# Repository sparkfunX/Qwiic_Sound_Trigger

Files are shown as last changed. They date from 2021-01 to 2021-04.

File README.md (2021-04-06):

# Qwiic Sound Trigger

A sound trigger which you can use on its own, or as part of your Qwiic system.

Qwiic Sound Trigger (SPX-17979) (https://www.sparkfun.com/products/17979)

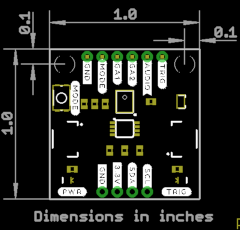
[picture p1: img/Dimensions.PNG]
Qwiic Sound Trigger (SPX-17979)


[Qwiic Sound Trigger (SPX-17979)](https://www.sparkfun.com/products/17979)

The Qwiic Sound Trigger is based on the VM1010 from Vesper Technologies and the TI PCA9536 GPIO expander.

The VM1010 is a clever little device which can be placed into a very low power "Wake On Sound" mode. When it detects a sound,
it wakes up and pulls its TRIG (D<sub>OUT</sub>) pin high. The VM1010 can then be placed into "Normal" mode by pulling the
MODE pin low; it then functions as a regular microphone. The analog microphone signal is available on the AUDIO (V<sub>OUT</sub>) pin.
All of this happens really quickly, within 50 _microseconds_ (_much_ faster than a capacitive MEMS microphone), so you don't miss
the start of the audio signal.

The noise threshold required to wake the VM1010 can be programmed via the resistance between pins GA1 and GA2. By default, the 20K
resistor on the breakout sets the noise threshold to close to the minimum (most sensitive) setting. You can increase the threshold
to maximum (least sensitive) by cutting the THRESH jumper. You can set it mid-way by adding your own resistor between breakout pins GA1 and GA2.

If you are using the VM1010 purely as a sound trigger, you need to reset it after each event by: pushing the MODE button;
pulling the MODE breakout pin low; or using the Qwiic bus to instruct the PCA9536 to pull the MODE signal low (the VM1010 MODE signal is connected to GPIO0).

You can use the TRIG (D<sub>OUT</sub>) breakout pin to generate an interrupt on your microcontroller. Or you can read (poll) its state via
the PCA9536 (the TRIG (D<sub>OUT</sub>) signal is connected to GPIO1).

There are two LEDs: one to indicate if the breakout is powered; and a second to show when a sound trigger has taken place. You can disable
either or both LEDs by cutting the LED jumpers on the back of the breakout.

As usual, the breakout includes I<sup>2</sup>C pull-up resistors. You can disable those if you need to by cutting the I2C jumpers.

The [**/Examples**](./Examples) folder contains two example sketches for the Arduino IDE:
- Example1 is a very simple example showing how to read the sound trigger TRIG signal via the PCA9536 GPIO1 pin and reset it via the MODE signal and GPIO2
- Example2 is a more complex example showing how you can capture and log the rising edge of the sound event with _nanosecond_ resolution using a ZED-F9P GNSS receiver

The [**/Utils**](./Utils) folder contains Python tools which can process the UBX TIM_TM2 data logged by Example2 and calculate the location of the sound events.

## Repository Contents
- [**/Examples**](./Examples) - Example sketches (.ino). Run these from the Arduino IDE
- [**/Utils**](./Utils) - Python tools to process the UBX TIM_TM2 data logged by Example2
- [**/Documents**](./Documents) - Datasheets etc. for both the VM1010 and PCA9536
- [**/Hardware**](./Hardware) - Eagle schematic and PCB design files
- [**LICENSE.md**](./LICENSE.md) contains the licence information

## Library

- **[SparkFun PCA9536 Arduino Library](https://github.com/sparkfun/SparkFun_PCA9536_Arduino_Library)** - Library for the TI PCA9536 4-Bit GPIO Expander

**_Your friends at SparkFun_**

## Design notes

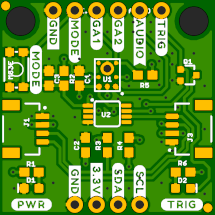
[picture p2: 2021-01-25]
img/Top.PNG

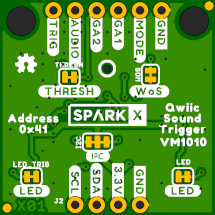
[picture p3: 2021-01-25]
img/Bottom.PNG

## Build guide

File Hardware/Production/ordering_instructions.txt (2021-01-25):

panel size, 143x143mm
PCB thickness, 1.6mm
number of layers, 2
soldermask color, Black
silkscreen color, White
oz copper, 1oz
finish, HASL lead free
stencils, top
pcs per panel, 25
min trace width, 0.2540mm / 0.0100in
min drill size, 0.3000mm / 0.0118in

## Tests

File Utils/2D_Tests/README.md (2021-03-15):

# 2D Tests

**python ..\Sound_Trigger_Analyzer_2D.py 1_TIM_TM2_A.ubx 1_TIM_TM2_B.ubx 1_TIM_TM2_C.ubx 10.0 11.0 8.0 20.0**

- Distance from sensor A to sensor B is 10.0m
- Distance from sensor A to sensor C is 11.0m
- Distance from sensor B to sensor C is 8.0m

- Test 1: Source located at (4.000,3.000)
- Test 2: Source located at (7.000,4.000)
- Test 3: Source located at (9.000,1.000) - i.e. East of C

**python ..\Sound_Trigger_Analyzer_2D.py 4_TIM_TM2_A.ubx 4_TIM_TM2_B.ubx 4_TIM_TM2_C.ubx 10.0 10.0 10.0 20.0**

- Distance from sensor A to sensor B is 10.0m
- Distance from sensor A to sensor C is 10.0m
- Distance from sensor B to sensor C is 10.0m

- Test 4: Source located at (5.000,2.887) - i.e. center of the triangle
- Test 5: Source located at (0.000,5.7735) - i.e. directly North of A on the circumference of the circle - outside of the triangle ABC
- Test 6: Source located at (-0.7735,2.8868) - i.e. West of A on the circumference of the circle - **FAILS**
- Test 7: Source located at (5.000,-2.8868) - i.e. due South of C on the circumference of the circle - **FAILS**

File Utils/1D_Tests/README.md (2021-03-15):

# 1D Tests

**python ..\Sound_Trigger_Analyzer_1D.py 1_TIM_TM2_1.ubx 1_TIM_TM2_2.ubx 10.0 20.0**

- Distance from sensor 1 to sensor 2 is 10.0m

- Test 1: Source located at sensor 1
- Test 2: Source located 3m from sensor 1
- Test 3: Source located 5m from sensor 1
- Test 4: Source located 7m from sensor 1
- Test 5: Source located at sensor 2

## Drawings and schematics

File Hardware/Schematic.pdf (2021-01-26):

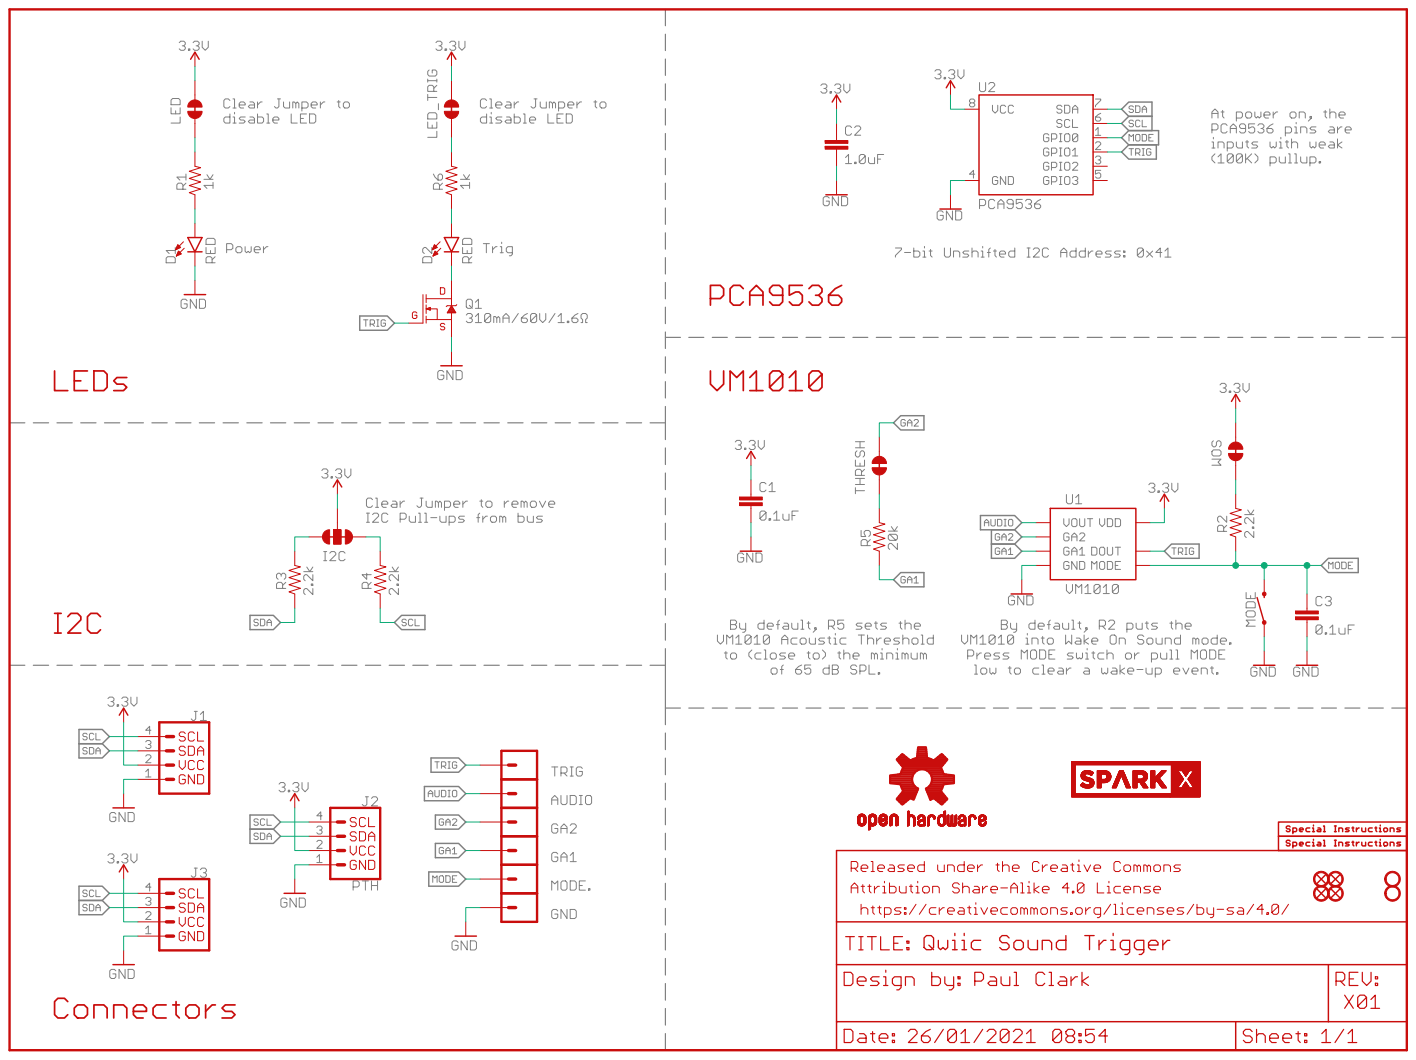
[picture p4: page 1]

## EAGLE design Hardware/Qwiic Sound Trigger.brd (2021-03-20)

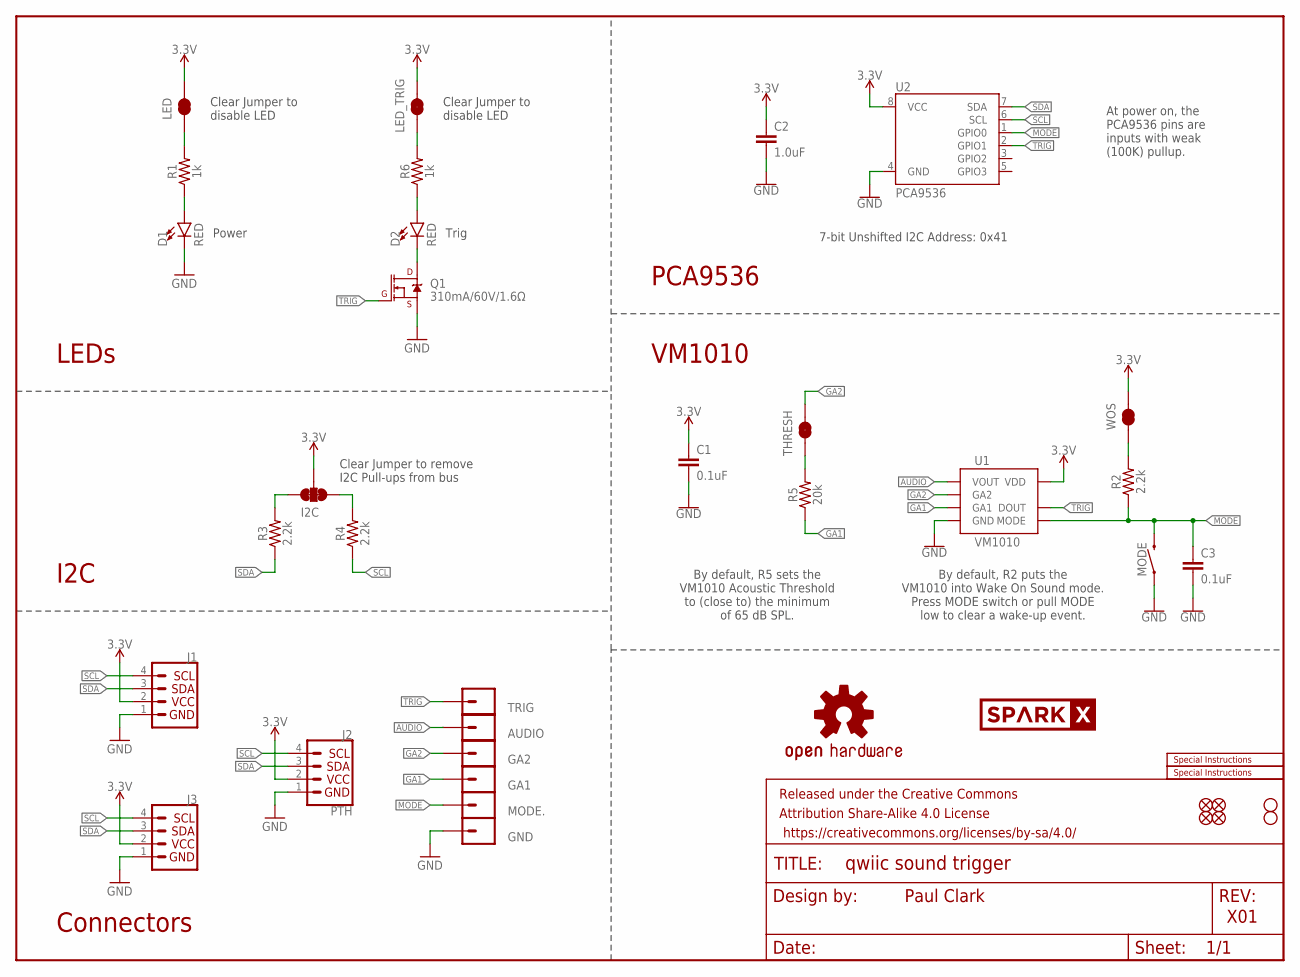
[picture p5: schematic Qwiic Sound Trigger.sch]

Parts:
AUDIO: CONN_01PTH_NO_SILK_YES_STOP; 1X01_NO_SILK
C1, C3: 0.1uF; 0603
C2: 1.0uF; 0603
D1, D2: RED; LED-0603
FRAME1: FRAME-LETTER; CREATIVE_COMMONS
GA1, GA2: CONN_01PTH_NO_SILK_YES_STOP; 1X01_NO_SILK
GND: CONN_01PTH_NO_SILK_YES_STOP; 1X01_NO_SILK
I2C: JUMPER-SMT_3_2-NC_TRACE_SILK; SMT-JUMPER_3_2-NC_TRACE_SILK
J1, J3: Qwiic Right Angle; JST04_1MM_RA
J2: PTH; 1X04_NO_SILK
JP1, JP2, JP5, JP6: FIDUCIAL1X2; FIDUCIAL-1X2
JP3, JP4: STAND-OFF
LED: JUMPER-SMT_2_NC_TRACE_SILK; SMT-JUMPER_2_NC_TRACE_SILK
LED_TRIG: JUMPER-SMT_2_NC_TRACE_SILK; SMT-JUMPER_2_NC_TRACE_SILK
LOGO1: OSHW-LOGOMINI; OSHW-LOGO-MINI
LOGO2: SPECIAL_INSTRUCTIONS-ORDERING; ORDERING_INSTRUCTIONS
LOGO3: SPECIAL_INSTRUCTIONS-PRODUCTION; PRODUCTION_INSTRUCTIONS
MODE: MOMENTARY-SWITCH-SPST-SMD-4.6X2.8MM; TACTILE_SWITCH_SMD_4.6X2.8MM
MODE.: CONN_01PTH_NO_SILK_YES_STOP; 1X01_NO_SILK
Q1: 310mA/60V/1.6Ω; SOT323
R1, R6: 1k; 0603
R2, R3, R4: 2.2k; 0603
R5: 20k; 0603
THRESH: JUMPER-SMT_2_NC_TRACE_SILK; SMT-JUMPER_2_NC_TRACE_SILK
TRIG: CONN_01PTH_NO_SILK_YES_STOP; 1X01_NO_SILK
U1: VM1010
U2: PCA9536; MSOP8
U$2: SPARKX-LOGO4; SPARKX-MEDIUM
WOS: JUMPER-SMT_2_NC_TRACE_SILK; SMT-JUMPER_2_NC_TRACE_SILK

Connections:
3.3V: C1.1, C2.1, I2C.2, J1.2, J2.2, J3.2, LED.2, LED_TRIG.2, U1.6 (VDD), U2.8 (VCC), WOS.2
AUDIO: AUDIO.1, U1.1 (VOUT)
GA1: GA1.1, R5.1, U1.3 (GA1)
GA2: GA2.1, THRESH.2, U1.2 (GA2)
GND: C1.2, C2.2, C3.2, D1.C, GND.1, J1.1, J2.1, J3.1, MODE.1, MODE.2 (1), Q1.2 (S), U1.4 (GND), U1.8 (GND), U2.4 (GND)
MODE: C3.1, MODE.3 (2), MODE.4 (2), MODE..1, R2.1, U1.5 (MODE), U2.1 (GPIO0)
unnamed: I2C.1, R4.2
unnamed: I2C.3, R3.2
unnamed: D1.A, R1.1
unnamed: LED.1, R1.2
unnamed: R2.2, WOS.1
unnamed: R5.2, THRESH.1
unnamed: D2.A, R6.1
unnamed: LED_TRIG.1, R6.2
unnamed: D2.C, Q1.3 (D)
SCL: J1.4, J2.4, J3.4, R4.1, U2.6 (SCL)
SDA: J1.3, J2.3, J3.3, R3.1, U2.7 (SDA)
TRIG: Q1.1 (G), TRIG.1, U1.7 (DOUT), U2.2 (GPIO1)

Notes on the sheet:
Paul Clark
X01
Clear Jumper to remove I2C Pull-ups from bus
Power
7-bit Unshifted I2C Address: 0x41
Connectors
At power on, the PCA9536 pins are inputs with weak (100K) pullup.
Clear Jumper to disable LED
LEDs
I2C
PCA9536
VM1010
By default, R2 puts the VM1010 into Wake On Sound mode. Press MODE switch or pull MODE low to clear a wake-up event.
By default, R5 sets the VM1010 Acoustic Threshold to (close to) the minimum of 65 dB SPL.
Trig

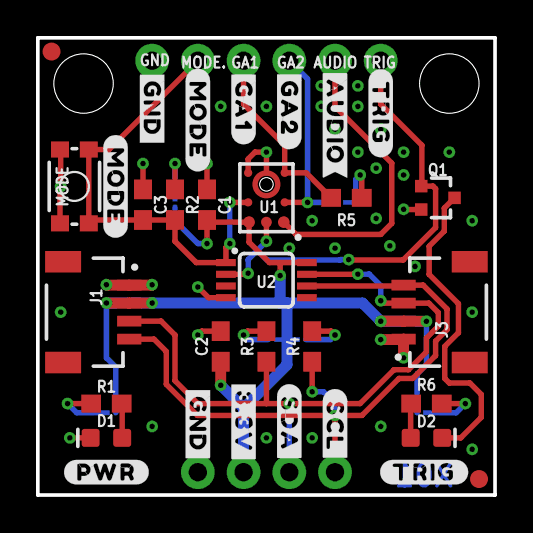
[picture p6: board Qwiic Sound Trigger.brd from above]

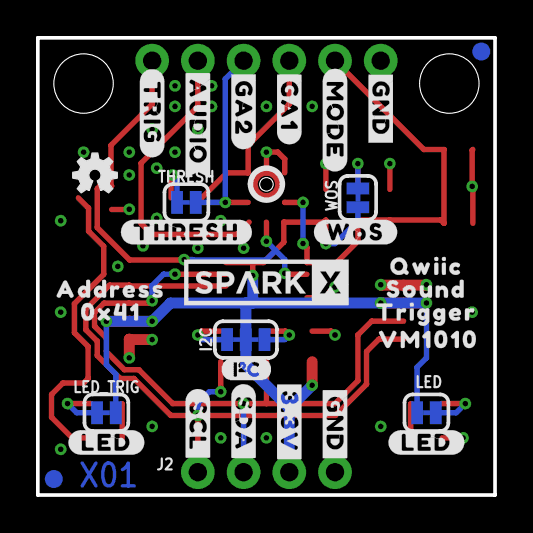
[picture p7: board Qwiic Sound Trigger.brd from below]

Board: 2 copper layers, 25.4 x 25.4 mm, 74 parts (31 on the bottom side), 18 nets.

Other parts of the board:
U$1, U$3: #GA1#0
U$4, U$5: #GA2#0
U$6, U$7: #AUDIO#0
U$8, U$9, U$25: #MODE#0
U$10: I_SUPER2_C-()-03
U$11, U$12, U$35: #TRIG#0
U$13: #PWR#0
U$14, U$36: #LED#0
U$15: #THRESH#0
U$16: #WOS#0
U$17, U$18, U$38, U$39: #GND#0
U$19, U$20: #3#3V#0
U$21, U$22: #SDA#0
U$23, U$24: #SCL#0
U$29: QWIIC0
U$30: SOUND0
U$31: TRIGGER0
U$32: VM10100
U$33: ADDRESS0
U$34: 0X410

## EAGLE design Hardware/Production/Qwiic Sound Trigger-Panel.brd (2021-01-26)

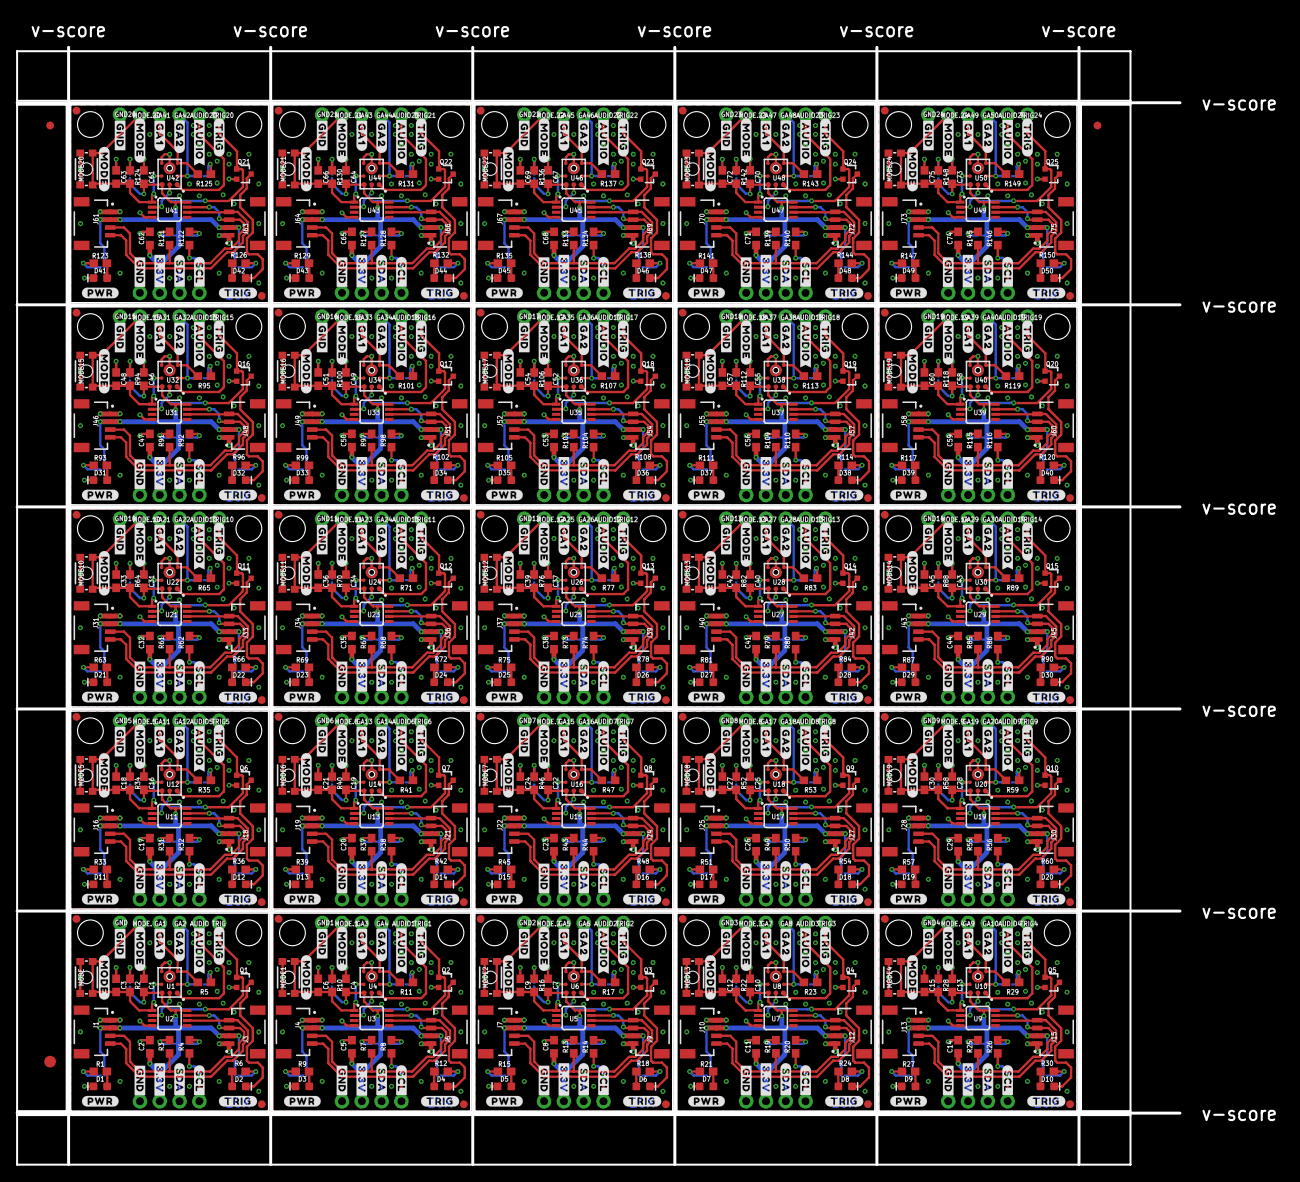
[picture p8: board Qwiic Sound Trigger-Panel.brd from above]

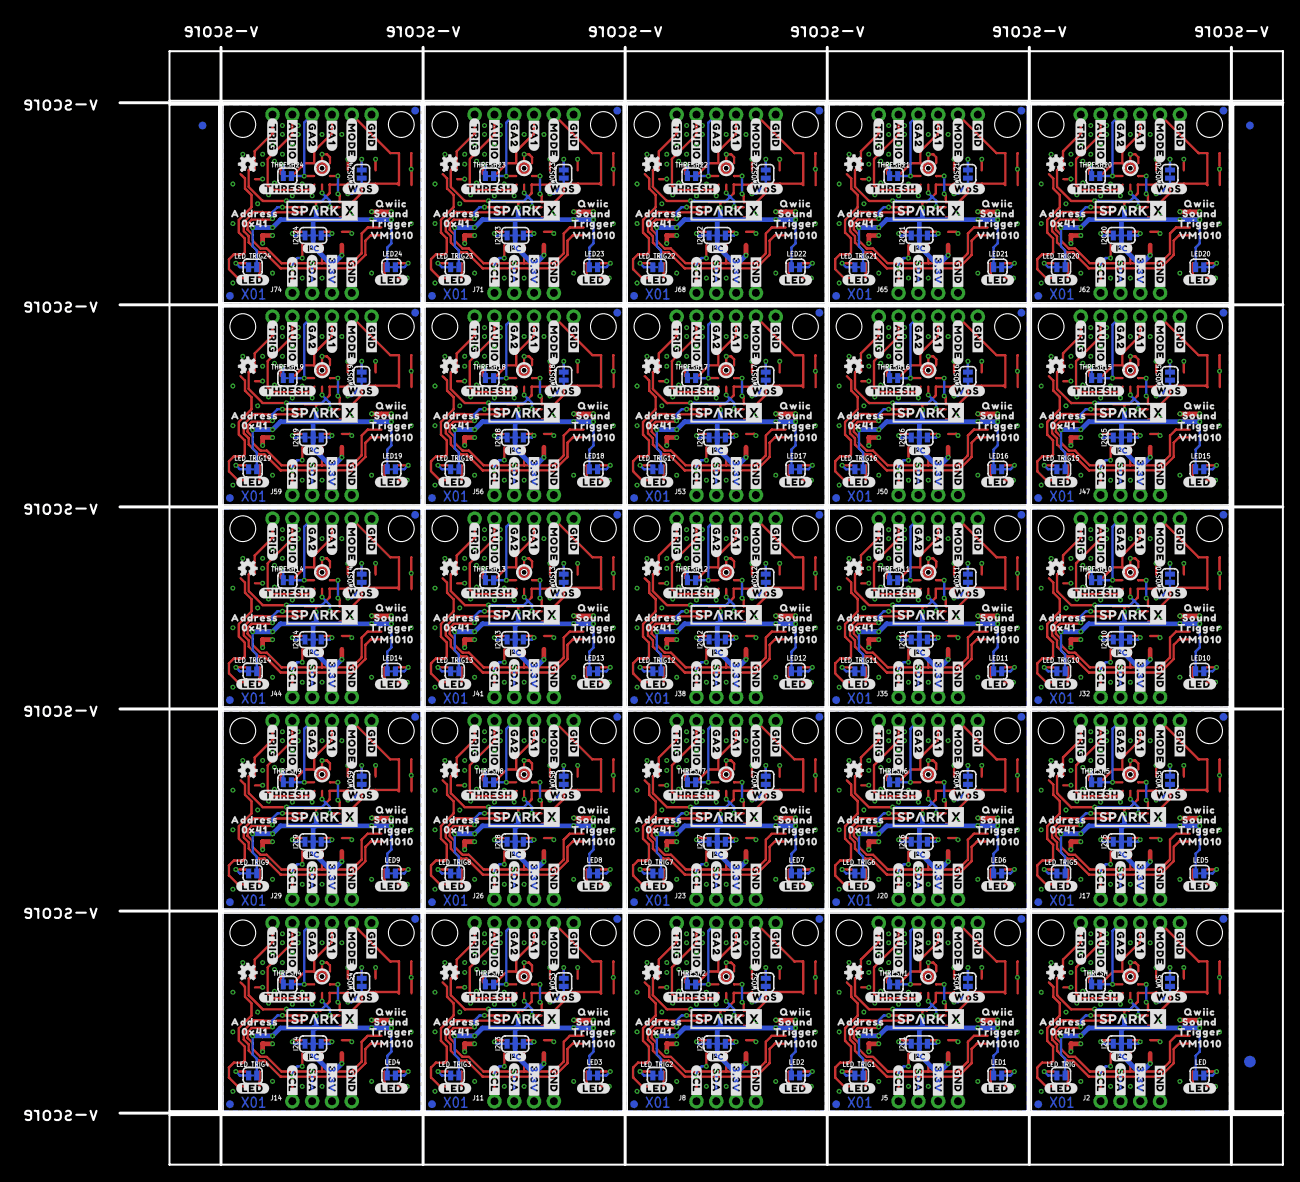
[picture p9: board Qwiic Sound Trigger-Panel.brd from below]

Board: 2 copper layers, 149.1 x 143.3 mm, 1831 parts (778 on the bottom side), 450 nets.

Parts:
AUDIO, AUDIO1, AUDIO2, AUDIO3, AUDIO4, AUDIO5, AUDIO6, AUDIO7, AUDIO8, AUDIO9, AUDIO10, AUDIO11, AUDIO12, AUDIO13, AUDIO14, AUDIO15, AUDIO16, AUDIO17, AUDIO18, AUDIO19, AUDIO20, AUDIO21, AUDIO22, AUDIO23, AUDIO24: 1X01_NO_SILK
C1, C3, C4, C6, C7, C9, C10, C12, C13, C15, C16, C18, C19, C21, C22, C24, C25, C27, C28, C30, C31, C33, C34, C36, C37, C39, C40, C42, C43, C45, C46, C48, C49, C51, C52, C54, C55, C57, C58, C60, C61, C63, C64, C66, C67, C69, C70, C72, C73, C75: 0.1uF; 0603
C2, C5, C8, C11, C14, C17, C20, C23, C26, C29, C32, C35, C38, C41, C44, C47, C50, C53, C56, C59, C62, C65, C68, C71, C74: 1.0uF; 0603
D1, D2, D3, D4, D5, D6, D7, D8, D9, D10, D11, D12, D13, D14, D15, D16, D17, D18, D19, D20, D21, D22, D23, D24, D25, D26, D27, D28, D29, D30, D31, D32, D33, D34, D35, D36, D37, D38, D39, D40, D41, D42, D43, D44, D45, D46, D47, D48, D49, D50: RED; LED-0603
E$1, E$2, E$3, E$4: FIDUCIAL-1X2
E$5, E$6: FIDUCIAL-1.5X3
GA1, GA2, GA3, GA4, GA5, GA6, GA7, GA8, GA9, GA10, GA11, GA12, GA13, GA14, GA15, GA16, GA17, GA18, GA19, GA20, GA21, GA22, GA23, GA24, GA25, GA26, GA27, GA28, GA29, GA30, GA31, GA32, GA33, GA34, GA35, GA36, GA37, GA38, GA39, GA40, GA41, GA42, GA43, GA44, GA45, GA46, GA47, GA48, GA49, GA50: 1X01_NO_SILK
GND, GND1, GND2, GND3, GND4, GND5, GND6, GND7, GND8, GND9, GND10, GND11, GND12, GND13, GND14, GND15, GND16, GND17, GND18, GND19, GND20, GND21, GND22, GND23, GND24: 1X01_NO_SILK
I2C, I2C1, I2C2, I2C3, I2C4, I2C5, I2C6, I2C7, I2C8, I2C9, I2C10, I2C11, I2C12, I2C13, I2C14, I2C15, I2C16, I2C17, I2C18, I2C19, I2C20, I2C21, I2C22, I2C23, I2C24: JUMPER-SMT_3_2-NC_TRACE_SILK; SMT-JUMPER_3_2-NC_TRACE_SILK
J1, J3, J4, J6, J7, J9, J10, J12, J13, J15, J16, J18, J19, J21, J22, J24, J25, J27, J28, J30, J31, J33, J34, J36, J37, J39, J40, J42, J43, J45, J46, J48, J49, J51, J52, J54, J55, J57, J58, J60, J61, J63, J64, J66, J67, J69, J70, J72, J73, J75: Qwiic Right Angle; JST04_1MM_RA
J2, J5, J8, J11, J14, J17, J20, J23, J26, J29, J32, J35, J38, J41, J44, J47, J50, J53, J56, J59, J62, J65, J68, J71, J74: PTH; 1X04_NO_SILK
JP1, JP2, JP5, JP6, JP9, JP10, JP11, JP12, JP15, JP16, JP17, JP18, JP21, JP22, JP23, JP24, JP27, JP28, JP29, JP30, JP33, JP34, JP35, JP36, JP39, JP40, JP41, JP42, JP45, JP46, JP47, JP48, JP51, JP52, JP53, JP54, JP57, JP58, JP59, JP60, JP63, JP64, JP65, JP66, JP69, JP70, JP71, JP72, JP75, JP76, JP77, JP78, JP81, JP82, JP83, JP84, JP87, JP88, JP89, JP90, JP93, JP94, JP95, JP96, JP99, JP100, JP101, JP102, JP105, JP106, JP107, JP108, JP111, JP112, JP113, JP114, JP117, JP118, JP119, JP120, JP123, JP124, JP125, JP126, JP129, JP130, JP131, JP132, JP135, JP136, JP137, JP138, JP141, JP142, JP143, JP144, JP147, JP148, JP149, JP150: FIDUCIAL1X2; FIDUCIAL-1X2
JP3, JP4, JP7, JP8, JP13, JP14, JP19, JP20, JP25, JP26, JP31, JP32, JP37, JP38, JP43, JP44, JP49, JP50, JP55, JP56, JP61, JP62, JP67, JP68, JP73, JP74, JP79, JP80, JP85, JP86, JP91, JP92, JP97, JP98, JP103, JP104, JP109, JP110, JP115, JP116, JP121, JP122, JP127, JP128, JP133, JP134, JP139, JP140, JP145, JP146: STAND-OFF
LED, LED1, LED2, LED3, LED4, LED5, LED6, LED7, LED8, LED9, LED10, LED11, LED12, LED13, LED14, LED15, LED16, LED17, LED18, LED19, LED20, LED21, LED22, LED23, LED24: SMT-JUMPER_2_NC_TRACE_SILK
LED_TRIG, LED_TRIG1, LED_TRIG2, LED_TRIG3, LED_TRIG4, LED_TRIG5, LED_TRIG6, LED_TRIG7, LED_TRIG8, LED_TRIG9, LED_TRIG10, LED_TRIG11, LED_TRIG12, LED_TRIG13, LED_TRIG14, LED_TRIG15, LED_TRIG16, LED_TRIG17, LED_TRIG18, LED_TRIG19, LED_TRIG20, LED_TRIG21, LED_TRIG22, LED_TRIG23, LED_TRIG24: SMT-JUMPER_2_NC_TRACE_SILK
LOGO1, LOGO4, LOGO7, LOGO10, LOGO13, LOGO16, LOGO19, LOGO22, LOGO25, LOGO28, LOGO31, LOGO34, LOGO37, LOGO40, LOGO43, LOGO46, LOGO49, LOGO52, LOGO55, LOGO58, LOGO61, LOGO64, LOGO67, LOGO70, LOGO73: OSHW-LOGOMINI; OSHW-LOGO-MINI
LOGO2, LOGO5, LOGO8, LOGO11, LOGO14, LOGO17, LOGO20, LOGO23, LOGO26, LOGO29, LOGO32, LOGO35, LOGO38, LOGO41, LOGO44, LOGO47, LOGO50, LOGO53, LOGO56, LOGO59, LOGO62, LOGO65, LOGO68, LOGO71, LOGO74: SPECIAL_INSTRUCTIONS-ORDERING; ORDERING_INSTRUCTIONS
LOGO3, LOGO6, LOGO9, LOGO12, LOGO15, LOGO18, LOGO21, LOGO24, LOGO27, LOGO30, LOGO33, LOGO36, LOGO39, LOGO42, LOGO45, LOGO48, LOGO51, LOGO54, LOGO57, LOGO60, LOGO63, LOGO66, LOGO69, LOGO72, LOGO75: SPECIAL_INSTRUCTIONS-PRODUCTION; PRODUCTION_INSTRUCTIONS
MODE, MODE1, MODE2, MODE3, MODE4, MODE5, MODE6, MODE7, MODE8, MODE9, MODE10, MODE11, MODE12, MODE13, MODE14, MODE15, MODE16, MODE17, MODE18, MODE19, MODE20, MODE21, MODE22, MODE23, MODE24: MOMENTARY-SWITCH-SPST-SMD-4.6X2.8MM; TACTILE_SWITCH_SMD_4.6X2.8MM
MODE., MODE.1, MODE.2, MODE.3, MODE.4, MODE.5, MODE.6, MODE.7, MODE.8, MODE.9, MODE.10, MODE.11, MODE.12, MODE.13, MODE.14, MODE.15, MODE.16, MODE.17, MODE.18, MODE.19, MODE.20, MODE.21, MODE.22, MODE.23, MODE.24: 1X01_NO_SILK
Q1, Q2, Q3, Q4, Q5, Q6, Q7, Q8, Q9, Q10, Q11, Q12, Q13, Q14, Q15, Q16, Q17, Q18, Q19, Q20, Q21, Q22, Q23, Q24, Q25: 310mA/60V/1.6Ω; SOT323
R1, R6, R9, R12, R15, R18, R21, R24, R27, R30, R33, R36, R39, R42, R45, R48, R51, R54, R57, R60, R63, R66, R69, R72, R75, R78, R81, R84, R87, R90, R93, R96, R99, R102, R105, R108, R111, R114, R117, R120, R123, R126, R129, R132, R135, R138, R141, R144, R147, R150: 1k; 0603
R2, R3, R4, R7, R8, R10, R13, R14, R16, R19, R20, R22, R25, R26, R28, R31, R32, R34, R37, R38, R40, R43, R44, R46, R49, R50, R52, R55, R56, R58, R61, R62, R64, R67, R68, R70, R73, R74, R76, R79, R80, R82, R85, R86, R88, R91, R92, R94, R97, R98, R100, R103, R104, R106, R109, R110, R112, R115, R116, R118, R121, R122, R124, R127, R128, R130, R133, R134, R136, R139, R140, R142, R145, R146, R148: 2.2k; 0603
R5, R11, R17, R23, R29, R35, R41, R47, R53, R59, R65, R71, R77, R83, R89, R95, R101, R107, R113, R119, R125, R131, R137, R143, R149: 20k; 0603
THRESH, THRESH1, THRESH2, THRESH3, THRESH4, THRESH5, THRESH6, THRESH7, THRESH8, THRESH9, THRESH10, THRESH11, THRESH12, THRESH13, THRESH14, THRESH15, THRESH16, THRESH17, THRESH18, THRESH19, THRESH20, THRESH21, THRESH22, THRESH23, THRESH24: SMT-JUMPER_2_NC_TRACE_SILK
TRIG, TRIG1, TRIG2, TRIG3, TRIG4, TRIG5, TRIG6, TRIG7, TRIG8, TRIG9, TRIG10, TRIG11, TRIG12, TRIG13, TRIG14, TRIG15, TRIG16, TRIG17, TRIG18, TRIG19, TRIG20, TRIG21, TRIG22, TRIG23, TRIG24: 1X01_NO_SILK
U1, U4, U6, U8, U10, U12, U14, U16, U18, U20, U22, U24, U26, U28, U30, U32, U34, U36, U38, U40, U42, U44, U46, U48, U50: VM1010
U2, U3, U5, U7, U9, U11, U13, U15, U17, U19, U21, U23, U25, U27, U29, U31, U33, U35, U37, U39, U41, U43, U45, U47, U49: PCA9536; MSOP8
U$1, U$3, U$28, U$37, U$73, U$74, U$108, U$109, U$143, U$144, U$178, U$179, U$213, U$214, U$248, U$249, U$283, U$284, U$318, U$319, U$353, U$354, U$388, U$389, U$423, U$424, U$458, U$459, U$493, U$494, U$528, U$529, U$563, U$564, U$598, U$599, U$633, U$634, U$668, U$669, U$703, U$704, U$738, U$739, U$773, U$774, U$808, U$809, U$843, U$844: #GA1#0
U$2, U$26, U$71, U$106, U$141, U$176, U$211, U$246, U$281, U$316, U$351, U$386, U$421, U$456, U$491, U$526, U$561, U$596, U$631, U$666, U$701, U$736, U$771, U$806, U$841: SPARKX-LOGO4; SPARKX-MEDIUM
U$4, U$5, U$40, U$41, U$75, U$76, U$110, U$111, U$145, U$146, U$180, U$181, U$215, U$216, U$250, U$251, U$285, U$286, U$320, U$321, U$355, U$356, U$390, U$391, U$425, U$426, U$460, U$461, U$495, U$496, U$530, U$531, U$565, U$566, U$600, U$601, U$635, U$636, U$670, U$671, U$705, U$706, U$740, U$741, U$775, U$776, U$810, U$811, U$845, U$846: #GA2#0
U$6, U$7, U$42, U$43, U$77, U$78, U$112, U$113, U$147, U$148, U$182, U$183, U$217, U$218, U$252, U$253, U$287, U$288, U$322, U$323, U$357, U$358, U$392, U$393, U$427, U$428, U$462, U$463, U$497, U$498, U$532, U$533, U$567, U$568, U$602, U$603, U$637, U$638, U$672, U$673, U$707, U$708, U$742, U$743, U$777, U$778, U$812, U$813, U$847, U$848: #AUDIO#0
U$8, U$9, U$25, U$44, U$45, U$70, U$79, U$80, U$105, U$114, U$115, U$140, U$149, U$150, U$175, U$184, U$185, U$210, U$219, U$220, U$245, U$254, U$255, U$280, U$289, U$290, U$315, U$324, U$325, U$350, U$359, U$360, U$385, U$394, U$395, U$420, U$429, U$430, U$455, U$464, U$465, U$490, U$499, U$500, U$525, U$534, U$535, U$560, U$569, U$570, U$595, U$604, U$605, U$630, U$639, U$640, U$665, U$674, U$675, U$700, U$709, U$710, U$735, U$744, U$745, U$770, U$779, U$780, U$805, U$814, U$815, U$840, U$849, U$850, U$875: #MODE#0
U$10, U$27, U$72, U$107, U$142, U$177, U$212, U$247, U$282, U$317, U$352, U$387, U$422, U$457, U$492, U$527, U$562, U$597, U$632, U$667, U$702, U$737, U$772, U$807, U$842: I_SUPER2_C-()-03
U$11, U$12, U$35, U$46, U$47, U$66, U$81, U$82, U$101, U$116, U$117, U$136, U$151, U$152, U$171, U$186, U$187, U$206, U$221, U$222, U$241, U$256, U$257, U$276, U$291, U$292, U$311, U$326, U$327, U$346, U$361, U$362, U$381, U$396, U$397, U$416, U$431, U$432, U$451, U$466, U$467, U$486, U$501, U$502, U$521, U$536, U$537, U$556, U$571, U$572, U$591, U$606, U$607, U$626, U$641, U$642, U$661, U$676, U$677, U$696, U$711, U$712, U$731, U$746, U$747, U$766, U$781, U$782, U$801, U$816, U$817, U$836, U$851, U$852, U$871: #TRIG#0
U$13, U$48, U$83, U$118, U$153, U$188, U$223, U$258, U$293, U$328, U$363, U$398, U$433, U$468, U$503, U$538, U$573, U$608, U$643, U$678, U$713, U$748, U$783, U$818, U$853: #PWR#0
U$14, U$36, U$49, U$67, U$84, U$102, U$119, U$137, U$154, U$172, U$189, U$207, U$224, U$242, U$259, U$277, U$294, U$312, U$329, U$347, U$364, U$382, U$399, U$417, U$434, U$452, U$469, U$487, U$504, U$522, U$539, U$557, U$574, U$592, U$609, U$627, U$644, U$662, U$679, U$697, U$714, U$732, U$749, U$767, U$784, U$802, U$819, U$837, U$854, U$872: #LED#0
U$15, U$50, U$85, U$120, U$155, U$190, U$225, U$260, U$295, U$330, U$365, U$400, U$435, U$470, U$505, U$540, U$575, U$610, U$645, U$680, U$715, U$750, U$785, U$820, U$855: #THRESH#0
U$16, U$51, U$86, U$121, U$156, U$191, U$226, U$261, U$296, U$331, U$366, U$401, U$436, U$471, U$506, U$541, U$576, U$611, U$646, U$681, U$716, U$751, U$786, U$821, U$856: #WOS#0
U$17, U$18, U$38, U$39, U$52, U$53, U$68, U$69, U$87, U$88, U$103, U$104, U$122, U$123, U$138, U$139, U$157, U$158, U$173, U$174, U$192, U$193, U$208, U$209, U$227, U$228, U$243, U$244, U$262, U$263, U$278, U$279, U$297, U$298, U$313, U$314, U$332, U$333, U$348, U$349, U$367, U$368, U$383, U$384, U$402, U$403, U$418, U$419, U$437, U$438, U$453, U$454, U$472, U$473, U$488, U$489, U$507, U$508, U$523, U$524, U$542, U$543, U$558, U$559, U$577, U$578, U$593, U$594, U$612, U$613, U$628, U$629, U$647, U$648, U$663, U$664, U$682, U$683, U$698, U$699, U$717, U$718, U$733, U$734, U$752, U$753, U$768, U$769, U$787, U$788, U$803, U$804, U$822, U$823, U$838, U$839, U$857, U$858, U$873, U$874: #GND#0
U$19, U$20, U$54, U$55, U$89, U$90, U$124, U$125, U$159, U$160, U$194, U$195, U$229, U$230, U$264, U$265, U$299, U$300, U$334, U$335, U$369, U$370, U$404, U$405, U$439, U$440, U$474, U$475, U$509, U$510, U$544, U$545, U$579, U$580, U$614, U$615, U$649, U$650, U$684, U$685, U$719, U$720, U$754, U$755, U$789, U$790, U$824, U$825, U$859, U$860: #3#3V#0
U$21, U$22, U$56, U$57, U$91, U$92, U$126, U$127, U$161, U$162, U$196, U$197, U$231, U$232, U$266, U$267, U$301, U$302, U$336, U$337, U$371, U$372, U$406, U$407, U$441, U$442, U$476, U$477, U$511, U$512, U$546, U$547, U$581, U$582, U$616, U$617, U$651, U$652, U$686, U$687, U$721, U$722, U$756, U$757, U$791, U$792, U$826, U$827, U$861, U$862: #SDA#0
U$23, U$24, U$58, U$59, U$93, U$94, U$128, U$129, U$163, U$164, U$198, U$199, U$233, U$234, U$268, U$269, U$303, U$304, U$338, U$339, U$373, U$374, U$408, U$409, U$443, U$444, U$478, U$479, U$513, U$514, U$548, U$549, U$583, U$584, U$618, U$619, U$653, U$654, U$688, U$689, U$723, U$724, U$758, U$759, U$793, U$794, U$828, U$829, U$863, U$864: #SCL#0
U$29, U$60, U$95, U$130, U$165, U$200, U$235, U$270, U$305, U$340, U$375, U$410, U$445, U$480, U$515, U$550, U$585, U$620, U$655, U$690, U$725, U$760, U$795, U$830, U$865: QWIIC0
U$30, U$61, U$96, U$131, U$166, U$201, U$236, U$271, U$306, U$341, U$376, U$411, U$446, U$481, U$516, U$551, U$586, U$621, U$656, U$691, U$726, U$761, U$796, U$831, U$866: SOUND0
U$31, U$62, U$97, U$132, U$167, U$202, U$237, U$272, U$307, U$342, U$377, U$412, U$447, U$482, U$517, U$552, U$587, U$622, U$657, U$692, U$727, U$762, U$797, U$832, U$867: TRIGGER0
U$32, U$63, U$98, U$133, U$168, U$203, U$238, U$273, U$308, U$343, U$378, U$413, U$448, U$483, U$518, U$553, U$588, U$623, U$658, U$693, U$728, U$763, U$798, U$833, U$868: VM10100
U$33, U$64, U$99, U$134, U$169, U$204, U$239, U$274, U$309, U$344, U$379, U$414, U$449, U$484, U$519, U$554, U$589, U$624, U$659, U$694, U$729, U$764, U$799, U$834, U$869: ADDRESS0
U$34, U$65, U$100, U$135, U$170, U$205, U$240, U$275, U$310, U$345, U$380, U$415, U$450, U$485, U$520, U$555, U$590, U$625, U$660, U$695, U$730, U$765, U$800, U$835, U$870: 0X410
WOS, WOS1, WOS2, WOS3, WOS4, WOS5, WOS6, WOS7, WOS8, WOS9, WOS10, WOS11, WOS12, WOS13, WOS14, WOS15, WOS16, WOS17, WOS18, WOS19, WOS20, WOS21, WOS22, WOS23, WOS24: SMT-JUMPER_2_NC_TRACE_SILK

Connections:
3.3V: C1.1, C2.1, I2C.2, J1.2, J2.2, J3.2, LED.2, LED_TRIG.2, U1.6, U2.8, WOS.2
3.3V1: C4.1, C5.1, I2C1.2, J4.2, J5.2, J6.2, LED1.2, LED_TRIG1.2, U3.8, U4.6, WOS1.2
3.3V2: C7.1, C8.1, I2C2.2, J7.2, J8.2, J9.2, LED2.2, LED_TRIG2.2, U5.8, U6.6, WOS2.2
3.3V3: C10.1, C11.1, I2C3.2, J10.2, J11.2, J12.2, LED3.2, LED_TRIG3.2, U7.8, U8.6, WOS3.2
3.3V4: C13.1, C14.1, I2C4.2, J13.2, J14.2, J15.2, LED4.2, LED_TRIG4.2, U9.8, U10.6, WOS4.2
3.3V5: C16.1, C17.1, I2C5.2, J16.2, J17.2, J18.2, LED5.2, LED_TRIG5.2, U11.8, U12.6, WOS5.2
3.3V6: C19.1, C20.1, I2C6.2, J19.2, J20.2, J21.2, LED6.2, LED_TRIG6.2, U13.8, U14.6, WOS6.2
3.3V7: C22.1, C23.1, I2C7.2, J22.2, J23.2, J24.2, LED7.2, LED_TRIG7.2, U15.8, U16.6, WOS7.2
3.3V8: C25.1, C26.1, I2C8.2, J25.2, J26.2, J27.2, LED8.2, LED_TRIG8.2, U17.8, U18.6, WOS8.2
3.3V9: C28.1, C29.1, I2C9.2, J28.2, J29.2, J30.2, LED9.2, LED_TRIG9.2, U19.8, U20.6, WOS9.2
3.3V10: C31.1, C32.1, I2C10.2, J31.2, J32.2, J33.2, LED10.2, LED_TRIG10.2, U21.8, U22.6, WOS10.2
3.3V11: C34.1, C35.1, I2C11.2, J34.2, J35.2, J36.2, LED11.2, LED_TRIG11.2, U23.8, U24.6, WOS11.2
3.3V12: C37.1, C38.1, I2C12.2, J37.2, J38.2, J39.2, LED12.2, LED_TRIG12.2, U25.8, U26.6, WOS12.2
3.3V13: C40.1, C41.1, I2C13.2, J40.2, J41.2, J42.2, LED13.2, LED_TRIG13.2, U27.8, U28.6, WOS13.2
3.3V14: C43.1, C44.1, I2C14.2, J43.2, J44.2, J45.2, LED14.2, LED_TRIG14.2, U29.8, U30.6, WOS14.2
3.3V15: C46.1, C47.1, I2C15.2, J46.2, J47.2, J48.2, LED15.2, LED_TRIG15.2, U31.8, U32.6, WOS15.2
3.3V16: C49.1, C50.1, I2C16.2, J49.2, J50.2, J51.2, LED16.2, LED_TRIG16.2, U33.8, U34.6, WOS16.2
3.3V17: C52.1, C53.1, I2C17.2, J52.2, J53.2, J54.2, LED17.2, LED_TRIG17.2, U35.8, U36.6, WOS17.2
3.3V18: C55.1, C56.1, I2C18.2, J55.2, J56.2, J57.2, LED18.2, LED_TRIG18.2, U37.8, U38.6, WOS18.2
3.3V19: C58.1, C59.1, I2C19.2, J58.2, J59.2, J60.2, LED19.2, LED_TRIG19.2, U39.8, U40.6, WOS19.2
3.3V20: C61.1, C62.1, I2C20.2, J61.2, J62.2, J63.2, LED20.2, LED_TRIG20.2, U41.8, U42.6, WOS20.2
3.3V21: C64.1, C65.1, I2C21.2, J64.2, J65.2, J66.2, LED21.2, LED_TRIG21.2, U43.8, U44.6, WOS21.2
3.3V22: C67.1, C68.1, I2C22.2, J67.2, J68.2, J69.2, LED22.2, LED_TRIG22.2, U45.8, U46.6, WOS22.2
3.3V23: C70.1, C71.1, I2C23.2, J70.2, J71.2, J72.2, LED23.2, LED_TRIG23.2, U47.8, U48.6, WOS23.2
3.3V24: C73.1, C74.1, I2C24.2, J73.2, J74.2, J75.2, LED24.2, LED_TRIG24.2, U49.8, U50.6, WOS24.2
AUDIO: AUDIO.1, U1.1
AUDIO1: AUDIO1.1, U4.1
AUDIO2: AUDIO2.1, U6.1
AUDIO3: AUDIO3.1, U8.1
AUDIO4: AUDIO4.1, U10.1
AUDIO5: AUDIO5.1, U12.1
AUDIO6: AUDIO6.1, U14.1
AUDIO7: AUDIO7.1, U16.1
AUDIO8: AUDIO8.1, U18.1
AUDIO9: AUDIO9.1, U20.1
AUDIO10: AUDIO10.1, U22.1
AUDIO11: AUDIO11.1, U24.1
AUDIO12: AUDIO12.1, U26.1
AUDIO13: AUDIO13.1, U28.1
AUDIO14: AUDIO14.1, U30.1
AUDIO15: AUDIO15.1, U32.1
AUDIO16: AUDIO16.1, U34.1
AUDIO17: AUDIO17.1, U36.1
AUDIO18: AUDIO18.1, U38.1
AUDIO19: AUDIO19.1, U40.1
AUDIO20: AUDIO20.1, U42.1
AUDIO21: AUDIO21.1, U44.1
AUDIO22: AUDIO22.1, U46.1
AUDIO23: AUDIO23.1, U48.1
AUDIO24: AUDIO24.1, U50.1
GA1: GA1.1, R5.1, U1.3
GA2: GA2.1, THRESH.2, U1.2
GA3: GA4.1, THRESH1.2, U4.2
GA4: GA3.1, R11.1, U4.3
GA5: GA6.1, THRESH2.2, U6.2
GA6: GA5.1, R17.1, U6.3
GA7: GA8.1, THRESH3.2, U8.2
GA8: GA7.1, R23.1, U8.3
GA9: GA10.1, THRESH4.2, U10.2
GA10: GA9.1, R29.1, U10.3
GA11: GA12.1, THRESH5.2, U12.2
GA12: GA11.1, R35.1, U12.3
GA13: GA14.1, THRESH6.2, U14.2
GA14: GA13.1, R41.1, U14.3
GA15: GA16.1, THRESH7.2, U16.2
GA16: GA15.1, R47.1, U16.3
GA17: GA18.1, THRESH8.2, U18.2
GA18: GA17.1, R53.1, U18.3
GA19: GA20.1, THRESH9.2, U20.2
GA20: GA19.1, R59.1, U20.3
GA21: GA22.1, THRESH10.2, U22.2
GA22: GA21.1, R65.1, U22.3
GA23: GA24.1, THRESH11.2, U24.2
GA24: GA23.1, R71.1, U24.3
GA25: GA26.1, THRESH12.2, U26.2
GA26: GA25.1, R77.1, U26.3
GA27: GA28.1, THRESH13.2, U28.2
GA28: GA27.1, R83.1, U28.3
GA29: GA30.1, THRESH14.2, U30.2
GA30: GA29.1, R89.1, U30.3
GA31: GA32.1, THRESH15.2, U32.2
GA32: GA31.1, R95.1, U32.3
GA33: GA34.1, THRESH16.2, U34.2
GA34: GA33.1, R101.1, U34.3
GA35: GA36.1, THRESH17.2, U36.2
GA36: GA35.1, R107.1, U36.3
GA37: GA38.1, THRESH18.2, U38.2
GA38: GA37.1, R113.1, U38.3
GA39: GA40.1, THRESH19.2, U40.2
GA40: GA39.1, R119.1, U40.3
GA41: GA42.1, THRESH20.2, U42.2
GA42: GA41.1, R125.1, U42.3
GA43: GA44.1, THRESH21.2, U44.2
GA44: GA43.1, R131.1, U44.3
GA45: GA46.1, THRESH22.2, U46.2
GA46: GA45.1, R137.1, U46.3
GA47: GA48.1, THRESH23.2, U48.2
GA48: GA47.1, R143.1, U48.3
GA49: GA50.1, THRESH24.2, U50.2
GA50: GA49.1, R149.1, U50.3
GND: C1.2, C2.2, C3.2, D1.C, GND.1, J1.1, J2.1, J3.1, MODE.1, MODE.2, Q1.2, U1.4, U1.8, U2.4
GND1: C4.2, C5.2, C6.2, D3.C, GND1.1, J4.1, J5.1, J6.1, MODE1.1, MODE1.2, Q2.2, U3.4, U4.4, U4.8
GND2: C7.2, C8.2, C9.2, D5.C, GND2.1, J7.1, J8.1, J9.1, MODE2.1, MODE2.2, Q3.2, U5.4, U6.4, U6.8
GND3: C10.2, C11.2, C12.2, D7.C, GND3.1, J10.1, J11.1, J12.1, MODE3.1, MODE3.2, Q4.2, U7.4, U8.4, U8.8
GND4: C13.2, C14.2, C15.2, D9.C, GND4.1, J13.1, J14.1, J15.1, MODE4.1, MODE4.2, Q5.2, U9.4, U10.4, U10.8
GND5: C16.2, C17.2, C18.2, D11.C, GND5.1, J16.1, J17.1, J18.1, MODE5.1, MODE5.2, Q6.2, U11.4, U12.4, U12.8
GND6: C19.2, C20.2, C21.2, D13.C, GND6.1, J19.1, J20.1, J21.1, MODE6.1, MODE6.2, Q7.2, U13.4, U14.4, U14.8
GND7: C22.2, C23.2, C24.2, D15.C, GND7.1, J22.1, J23.1, J24.1, MODE7.1, MODE7.2, Q8.2, U15.4, U16.4, U16.8
GND8: C25.2, C26.2, C27.2, D17.C, GND8.1, J25.1, J26.1, J27.1, MODE8.1, MODE8.2, Q9.2, U17.4, U18.4, U18.8
GND9: C28.2, C29.2, C30.2, D19.C, GND9.1, J28.1, J29.1, J30.1, MODE9.1, MODE9.2, Q10.2, U19.4, U20.4, U20.8
GND10: C31.2, C32.2, C33.2, D21.C, GND10.1, J31.1, J32.1, J33.1, MODE10.1, MODE10.2, Q11.2, U21.4, U22.4, U22.8
GND11: C34.2, C35.2, C36.2, D23.C, GND11.1, J34.1, J35.1, J36.1, MODE11.1, MODE11.2, Q12.2, U23.4, U24.4, U24.8
GND12: C37.2, C38.2, C39.2, D25.C, GND12.1, J37.1, J38.1, J39.1, MODE12.1, MODE12.2, Q13.2, U25.4, U26.4, U26.8
GND13: C40.2, C41.2, C42.2, D27.C, GND13.1, J40.1, J41.1, J42.1, MODE13.1, MODE13.2, Q14.2, U27.4, U28.4, U28.8
GND14: C43.2, C44.2, C45.2, D29.C, GND14.1, J43.1, J44.1, J45.1, MODE14.1, MODE14.2, Q15.2, U29.4, U30.4, U30.8
GND15: C46.2, C47.2, C48.2, D31.C, GND15.1, J46.1, J47.1, J48.1, MODE15.1, MODE15.2, Q16.2, U31.4, U32.4, U32.8
GND16: C49.2, C50.2, C51.2, D33.C, GND16.1, J49.1, J50.1, J51.1, MODE16.1, MODE16.2, Q17.2, U33.4, U34.4, U34.8
GND17: C52.2, C53.2, C54.2, D35.C, GND17.1, J52.1, J53.1, J54.1, MODE17.1, MODE17.2, Q18.2, U35.4, U36.4, U36.8
GND18: C55.2, C56.2, C57.2, D37.C, GND18.1, J55.1, J56.1, J57.1, MODE18.1, MODE18.2, Q19.2, U37.4, U38.4, U38.8
GND19: C58.2, C59.2, C60.2, D39.C, GND19.1, J58.1, J59.1, J60.1, MODE19.1, MODE19.2, Q20.2, U39.4, U40.4, U40.8
GND20: C61.2, C62.2, C63.2, D41.C, GND20.1, J61.1, J62.1, J63.1, MODE20.1, MODE20.2, Q21.2, U41.4, U42.4, U42.8
GND21: C64.2, C65.2, C66.2, D43.C, GND21.1, J64.1, J65.1, J66.1, MODE21.1, MODE21.2, Q22.2, U43.4, U44.4, U44.8
GND22: C67.2, C68.2, C69.2, D45.C, GND22.1, J67.1, J68.1, J69.1, MODE22.1, MODE22.2, Q23.2, U45.4, U46.4, U46.8
GND23: C70.2, C71.2, C72.2, D47.C, GND23.1, J70.1, J71.1, J72.1, MODE23.1, MODE23.2, Q24.2, U47.4, U48.4, U48.8
GND24: C73.2, C74.2, C75.2, D49.C, GND24.1, J73.1, J74.1, J75.1, MODE24.1, MODE24.2, Q25.2, U49.4, U50.4, U50.8
MODE: C3.1, MODE.3, MODE.4, MODE..1, R2.1, U1.5, U2.1
MODE1: C6.1, MODE1.3, MODE1.4, MODE.1.1, R10.1, U3.1, U4.5
MODE2: C9.1, MODE2.3, MODE2.4, MODE.2.1, R16.1, U5.1, U6.5
MODE3: C12.1, MODE3.3, MODE3.4, MODE.3.1, R22.1, U7.1, U8.5
MODE4: C15.1, MODE4.3, MODE4.4, MODE.4.1, R28.1, U9.1, U10.5
MODE5: C18.1, MODE5.3, MODE5.4, MODE.5.1, R34.1, U11.1, U12.5
MODE6: C21.1, MODE6.3, MODE6.4, MODE.6.1, R40.1, U13.1, U14.5
MODE7: C24.1, MODE7.3, MODE7.4, MODE.7.1, R46.1, U15.1, U16.5
MODE8: C27.1, MODE8.3, MODE8.4, MODE.8.1, R52.1, U17.1, U18.5
MODE9: C30.1, MODE9.3, MODE9.4, MODE.9.1, R58.1, U19.1, U20.5
MODE10: C33.1, MODE10.3, MODE10.4, MODE.10.1, R64.1, U21.1, U22.5
MODE11: C36.1, MODE11.3, MODE11.4, MODE.11.1, R70.1, U23.1, U24.5
MODE12: C39.1, MODE12.3, MODE12.4, MODE.12.1, R76.1, U25.1, U26.5
MODE13: C42.1, MODE13.3, MODE13.4, MODE.13.1, R82.1, U27.1, U28.5
MODE14: C45.1, MODE14.3, MODE14.4, MODE.14.1, R88.1, U29.1, U30.5
MODE15: C48.1, MODE15.3, MODE15.4, MODE.15.1, R94.1, U31.1, U32.5
MODE16: C51.1, MODE16.3, MODE16.4, MODE.16.1, R100.1, U33.1, U34.5
MODE17: C54.1, MODE17.3, MODE17.4, MODE.17.1, R106.1, U35.1, U36.5
MODE18: C57.1, MODE18.3, MODE18.4, MODE.18.1, R112.1, U37.1, U38.5
MODE19: C60.1, MODE19.3, MODE19.4, MODE.19.1, R118.1, U39.1, U40.5
MODE20: C63.1, MODE20.3, MODE20.4, MODE.20.1, R124.1, U41.1, U42.5
MODE21: C66.1, MODE21.3, MODE21.4, MODE.21.1, R130.1, U43.1, U44.5
MODE22: C69.1, MODE22.3, MODE22.4, MODE.22.1, R136.1, U45.1, U46.5
MODE23: C72.1, MODE23.3, MODE23.4, MODE.23.1, R142.1, U47.1, U48.5
MODE24: C75.1, MODE24.3, MODE24.4, MODE.24.1, R148.1, U49.1, U50.5
unnamed: I2C.1, R4.2
unnamed: I2C.3, R3.2
unnamed: D1.A, R1.1
unnamed: LED.1, R1.2
unnamed: R2.2, WOS.1
unnamed: R5.2, THRESH.1
unnamed: D2.A, R6.1
unnamed: LED_TRIG.1, R6.2
unnamed: D2.C, Q1.3
unnamed: I2C1.1, R8.2
unnamed: I2C1.3, R7.2
unnamed: D3.A, R9.1
unnamed: LED1.1, R9.2
unnamed: R10.2, WOS1.1
unnamed: R11.2, THRESH1.1
unnamed: D4.A, R12.1
unnamed: LED_TRIG1.1, R12.2
unnamed: D4.C, Q2.3
unnamed: I2C2.1, R14.2
unnamed: I2C2.3, R13.2
unnamed: D5.A, R15.1
unnamed: LED2.1, R15.2
unnamed: R16.2, WOS2.1
unnamed: R17.2, THRESH2.1
unnamed: D6.A, R18.1
unnamed: LED_TRIG2.1, R18.2
unnamed: D6.C, Q3.3
unnamed: I2C3.1, R20.2
unnamed: I2C3.3, R19.2
unnamed: D7.A, R21.1
unnamed: LED3.1, R21.2
unnamed: R22.2, WOS3.1
unnamed: R23.2, THRESH3.1
unnamed: D8.A, R24.1
unnamed: LED_TRIG3.1, R24.2
unnamed: D8.C, Q4.3
unnamed: I2C4.1, R26.2
unnamed: I2C4.3, R25.2
unnamed: D9.A, R27.1
unnamed: LED4.1, R27.2
unnamed: R28.2, WOS4.1
unnamed: R29.2, THRESH4.1
unnamed: D10.A, R30.1
unnamed: LED_TRIG4.1, R30.2
unnamed: D10.C, Q5.3
unnamed: I2C5.1, R32.2
unnamed: I2C5.3, R31.2
unnamed: D11.A, R33.1
unnamed: LED5.1, R33.2
unnamed: R34.2, WOS5.1
unnamed: R35.2, THRESH5.1
unnamed: D12.A, R36.1
unnamed: LED_TRIG5.1, R36.2
unnamed: D12.C, Q6.3
unnamed: I2C6.1, R38.2
unnamed: I2C6.3, R37.2
unnamed: D13.A, R39.1
unnamed: LED6.1, R39.2
unnamed: R40.2, WOS6.1
unnamed: R41.2, THRESH6.1
unnamed: D14.A, R42.1
unnamed: LED_TRIG6.1, R42.2
unnamed: D14.C, Q7.3
unnamed: I2C7.1, R44.2
unnamed: I2C7.3, R43.2
unnamed: D15.A, R45.1
unnamed: LED7.1, R45.2
unnamed: R46.2, WOS7.1
unnamed: R47.2, THRESH7.1
unnamed: D16.A, R48.1
unnamed: LED_TRIG7.1, R48.2
unnamed: D16.C, Q8.3
unnamed: I2C8.1, R50.2
unnamed: I2C8.3, R49.2
unnamed: D17.A, R51.1
unnamed: LED8.1, R51.2
unnamed: R52.2, WOS8.1
unnamed: R53.2, THRESH8.1
unnamed: D18.A, R54.1
unnamed: LED_TRIG8.1, R54.2
unnamed: D18.C, Q9.3
unnamed: I2C9.1, R56.2
unnamed: I2C9.3, R55.2
unnamed: D19.A, R57.1
unnamed: LED9.1, R57.2
unnamed: R58.2, WOS9.1
unnamed: R59.2, THRESH9.1
unnamed: D20.A, R60.1
unnamed: LED_TRIG9.1, R60.2
unnamed: D20.C, Q10.3
unnamed: I2C10.1, R62.2
unnamed: I2C10.3, R61.2
unnamed: D21.A, R63.1
unnamed: LED10.1, R63.2
unnamed: R64.2, WOS10.1
unnamed: R65.2, THRESH10.1
unnamed: D22.A, R66.1
unnamed: LED_TRIG10.1, R66.2
unnamed: D22.C, Q11.3
unnamed: I2C11.1, R68.2
unnamed: I2C11.3, R67.2
unnamed: D23.A, R69.1
unnamed: LED11.1, R69.2
unnamed: R70.2, WOS11.1
unnamed: R71.2, THRESH11.1
unnamed: D24.A, R72.1
unnamed: LED_TRIG11.1, R72.2
unnamed: D24.C, Q12.3
unnamed: I2C12.1, R74.2
unnamed: I2C12.3, R73.2
unnamed: D25.A, R75.1
unnamed: LED12.1, R75.2
unnamed: R76.2, WOS12.1
unnamed: R77.2, THRESH12.1
unnamed: D26.A, R78.1
unnamed: LED_TRIG12.1, R78.2
unnamed: D26.C, Q13.3
unnamed: I2C13.1, R80.2
unnamed: I2C13.3, R79.2
unnamed: D27.A, R81.1
unnamed: LED13.1, R81.2
unnamed: R82.2, WOS13.1
unnamed: R83.2, THRESH13.1
unnamed: D28.A, R84.1
unnamed: LED_TRIG13.1, R84.2
unnamed: D28.C, Q14.3
unnamed: I2C14.1, R86.2
unnamed: I2C14.3, R85.2
unnamed: D29.A, R87.1
unnamed: LED14.1, R87.2
unnamed: R88.2, WOS14.1
unnamed: R89.2, THRESH14.1
unnamed: D30.A, R90.1
unnamed: LED_TRIG14.1, R90.2
unnamed: D30.C, Q15.3
unnamed: I2C15.1, R92.2
unnamed: I2C15.3, R91.2
unnamed: D31.A, R93.1
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

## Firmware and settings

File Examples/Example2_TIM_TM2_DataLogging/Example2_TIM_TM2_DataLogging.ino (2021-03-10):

/*
  Qwiic Sound Trigger (VM1010) Example: accurate sound event logging with the u-blox ZED-F9P and UBX TIM_TM2 messages
  By: Paul Clark
  SparkFun Electronics
  Date: March 10th, 2021
  License: MIT. Please see LICENSE.md for more details.

  Feel like supporting our work? Buy a board from SparkFun!
  Qwiic Sound Trigger:                 https://www.sparkfun.com/products/17979
  ZED-F9P RTK SMA:                     https://www.sparkfun.com/products/16481
  ZED-F9P RTK2:                        https://www.sparkfun.com/products/15136
  MicroMod Data Logging Carrier Board: https://www.sparkfun.com/products/16829
  MicroMod Artemis Processor Board:    https://www.sparkfun.com/products/16401

  Based on the u-blox GNSS library example DataLoggingExample2_TIM_TM2:
  Configuring the ZED-F9P GNSS to automatically send TIM TM2 reports over I2C and log them to file on SD card
  
  This example shows how to configure the u-blox ZED-F9P GNSS to send TIM TM2 reports when a sound event is detected
  and automatically log the data to SD card in UBX format.

  This code is intended to be run on the MicroMod Data Logging Carrier Board using the Artemis Processor
  but can be adapted to any board by changing the chip select pin and SPI definitions.

  Hardware Connections:
  Solder a 6-way row of header pins to the Qwiic Sound Trigger so you can access the TRIG pin.
  Please see: https://learn.sparkfun.com/tutorials/micromod-data-logging-carrier-board-hookup-guide
  Insert the Artemis Processor into the MicroMod Data Logging Carrier Board and secure with the screw.
  Connect your ZED-F9P GNSS breakout to the Carrier Board using a Qwiic cable.
  Connect an antenna to your GNSS board.
  Insert a formatted micro-SD card into the socket on the Carrier Board.
  Connect the Qwiic Sound Trigger to the ZED-F9P using a second Qwiic cable.
  Use a jumper cable to connect the TRIG pin on the Qwiic Sound Trigger to the INT pin on the ZED-F9P breakout.
  Connect the Carrier Board to your computer using a USB-C cable.
  
  Ensure you have the SparkFun Apollo3 boards installed: http://boardsmanager/All#SparkFun_Apollo3
  This code has been tested using version 1.2.1 of the Apollo3 boards on Arduino IDE 1.8.13.
  Select "SparkFun Artemis MicroMod" as the board type.
  Press upload to upload the code onto the Artemis.
  Open the Serial Monitor at 115200 baud to see the output.

  To minimise I2C bus errors, it is a good idea to open the I2C pull-up split pad links on
  the MicroMod Data Logging Carrier Board and the u-blox module breakout and the Qwiic Sound Trigger.

  Each time the Qwiic Sound Trigger detects a sound, it pulls its TRIG pin high. The ZED-F9P will
  detect this on its INT pin and generate a TIM TM2 message. The Artemis will log the TIM TM2 message
  to SD card. You can then study the timing of the sound pulse with nanosecond resolution!
  The code will "debounce" the sound event and reset the VM1010 for the next sound event after 250ms.

  Note: TIM TM2 can only capture the timing of one rising edge and one falling edge per
  navigation solution. So with setNavigationFrequency set to 4Hz, we can only see the timing
  of one rising edge every 250ms. The code "debounces" each sound event to make sure there will
  only be one rising edge event per navigation solution.

  TIM TM2 messages are only produced when a rising or falling edge is detected on the INT pin.
  If you disconnect your TRIG to INT jumper wire, the messages will stop.

  Data is logged in u-blox UBX format. Please see the u-blox protocol specification for more details.
  You can replay and analyze the data using u-center:
  https://www.u-blox.com/en/product/u-center

*/

#include <SparkFun_PCA9536_Arduino_Library.h> // Click here to get the library: http://librarymanager/All#SparkFun_PCA9536
PCA9536 myTrigger;

#include <SPI.h>
#include <SD.h>
#include <Wire.h> //Needed for I2C to GNSS and PCA9536

#include <SparkFun_u-blox_GNSS_Arduino_Library.h> //Click here to get the library: http://librarymanager/All#SparkFun_u-blox_GNSS
SFE_UBLOX_GNSS myGNSS;

File myFile; //File that all GNSS data is written to

// This is hopefully a temporary fix for the MicroMod SAMD51 Processor Board
#if defined(ARDUINO_ARCH_SAMD)
#define BATTVIN3 BATT_VIN
#endif

// This is hopefully a temporary fix for the MicroMod ESP32 Processor Board
#if defined(ARDUINO_ARCH_ESP32)
#define CS SS
#define BATTVIN3 BATT_VIN
#endif

// This is hopefully a temporary fix for the MicroMod nRF52840 Processor Board
#if defined(ARDUINO_ARDUINO_NANO33BLE)
#define CS SS
#endif

#define sdChipSelect CS //Primary SPI Chip Select is CS for the MicroMod Artemis Processor. Adjust for your processor if necessary.
#define packetLength 36 // TIM TM2 is 28 + 8 bytes in length (including the sync chars, class, id, length and checksum bytes)
#define VM1010_MODE 0 // The VM1010 mode pin is connected to GPIO0 on the PCA9536
#define VM1010_TRIG 1 // The VM1010 trigger pin (Dout) is connected to GPIO1 on the PCA9536
#define LOW_BATT 3.2 // Define the low battery voltage as 3.2V

// Uncomment the next line to keep the SD file open between writes:
//  This will result in much faster writes, but there is a risk of the log file being left open when the power is disconnected
//  and the data being lost
//#define KEEP_FILE_OPEN // Uncomment this line to keep the SD file open between writes

int dotsPrinted = 0; // Print dots in rows of 50 while waiting for a TIM TM2 message

// Callback: printTIMTM2data will be called when new TIM TM2 data arrives
// See u-blox_structs.h for the full definition of UBX_TIM_TM2_data_t
//         _____  You can use any name you like for the callback. Use the same name when you call setAutoTIMTM2callback
//        /                  _____  This _must_ be UBX_TIM_TM2_data_t
//        |                 /                   _____ You can use any name you like for the struct
//        |                 |                  /
//        |                 |                  |
void printTIMTM2data(UBX_TIM_TM2_data_t ubxDataStruct)
{
  // It is the rising edge of the sound event (TRIG) which is important
  // The falling edge is less useful, as it will be "debounced" by the loop code

  if (ubxDataStruct.flags.bits.newRisingEdge) // 1 if a new rising edge was detected
  {
    Serial.println();
    Serial.print(F("Sound Event Detected!"));
  
    Serial.print(F("  Rising Edge Counter: ")); // Rising edge counter
    Serial.print(ubxDataStruct.count);
  
    Serial.print(F("  Time Of Week: "));
    Serial.print(ubxDataStruct.towMsR); // Time Of Week of rising edge (ms)
    Serial.print(F(" ms + "));
    Serial.print(ubxDataStruct.towSubMsR); // Millisecond fraction of Time Of Week of rising edge in nanoseconds
    Serial.println(F(" ns"));
  
    dotsPrinted = 0; // Reset dotsPrinted
  }
}

void setup()
{
  Serial.begin(115200);
  while (!Serial); //Wait for user to open terminal
  Serial.println("SparkFun Qwiic Sound Trigger Example");

  Wire.begin(); // Start I2C communication with the GNSS and the Qwiic Sound Trigger

  #if defined(AM_PART_APOLLO3)
  Wire.setPullups(0); // On the Artemis, we can disable the internal I2C pull-ups too to help reduce bus errors
  #endif

  pinMode(LED_BUILTIN, OUTPUT); // We will use LED_BUILTIN to indicate when data is being written to the SD card
  digitalWrite(LED_BUILTIN, LOW);

  pinMode(BATTVIN3, INPUT); // Use VIN/3 to detect low battery

  // Initialize the Sound Trigger PCA9536 with a begin function
  if (myTrigger.begin() == false)
  {
    Serial.println(F("Sound Trigger (PCA9536) not detected. Please check wiring. Freezing..."));
    while (1)
      ;
  }

  // Configure VM1010_TRIG (GPIO1) as an input for the VM1010 trigger signal (Dout)
  myTrigger.pinMode(VM1010_TRIG, INPUT);

  // Configure VM1010_MODE (GPIO0) as an input for now.
  // The pull-up resistor on the sound trigger will hold the VM1010 in "Wake On Sound" mode.
  // We will configure VM1010_MODE as an output when we want to pull the MODE pin low to clear the wake-up event.
  myTrigger.pinMode(VM1010_MODE, INPUT);

  Serial.println("Initializing SD card...");

  // See if the card is present and can be initialized:
  if (!SD.begin(sdChipSelect))
  {
    Serial.println("Card failed, or not present. Freezing...");
    // don't do anything more:
    while (1);
  }
  Serial.println("SD card initialized.");

  // Create or open a file called "TIM_TM2.ubx" on the SD card.
  // If the file already exists, the new data is appended to the end of the file.
  myFile = SD.open("TIM_TM2.ubx", FILE_WRITE);
  if(!myFile)
  {
    Serial.println(F("Failed to create UBX data file! Freezing..."));
    while (1);
  }
  #ifndef KEEP_FILE_OPEN
  myFile.close(); // Close the log file. It will be reopened when a sound event is detected.
  #endif

  //myGNSS.enableDebugging(); // Uncomment this line to enable helpful GNSS debug messages on Serial

  // TIM TM2 messages are 36 bytes long.
  // In this example, the data will arrive no faster than four messages per second.
  // So, setting the file buffer size to 361 bytes should be more than adequate.
  // I.e. room for ten messages plus an empty tail byte.
  myGNSS.setFileBufferSize(361); // setFileBufferSize must be called _before_ .begin

  if (myGNSS.begin() == false) //Connect to the u-blox module using Wire port
  {
    Serial.println(F("u-blox GNSS not detected at default I2C address. Please check wiring. Freezing..."));
    while (1);
  }

  // Uncomment the next line if you want to reset your GNSS module back to the default settings with 1Hz navigation rate
  // (This will also disable any "auto" messages that were enabled and saved by other examples and reduce the load on the I2C bus)
  //myGNSS.factoryDefault(); delay(5000);

  myGNSS.setI2COutput(COM_TYPE_UBX); //Set the I2C port to output UBX only (turn off NMEA noise)
  myGNSS.saveConfigSelective(VAL_CFG_SUBSEC_IOPORT); //Save (only) the communications port settings to flash and BBR

  myGNSS.setNavigationFrequency(4); //Produce four navigation solutions per second

  myGNSS.setAutoTIMTM2callback(&printTIMTM2data); // Enable automatic TIM TM2 messages with callback to printTIMTM2data

  myGNSS.logTIMTM2(); // Enable TIM TM2 data logging

  while (Serial.available()) // Make sure the Serial buffer is empty
  {
    Serial.read();
  }

  Serial.println(F("Press any key to stop logging."));

  resetSoundTrigger(); // Reset the sound trigger - in case it has already been triggered
}

void resetSoundTrigger()
{
  // Reset the sound event by:
  myTrigger.digitalWrite(VM1010_MODE, LOW); // Get ready to pull the VM1010 MODE pin low
  myTrigger.pinMode(VM1010_MODE, OUTPUT); // Change the PCA9536 GPIO0 pin to an output. It will pull the VM1010 MODE pin low
  myTrigger.pinMode(VM1010_MODE, INPUT); // Change the PCA9536 GPIO0 pin back to an input (with pull-up), so it will not 'fight' the mode button  
}

void loop()
{
  myGNSS.checkUblox(); // Check for the arrival of new data and process it.
  myGNSS.checkCallbacks(); // Check if any callbacks are waiting to be processed.

  // Check to see if a new packetLength-byte TIM TM2 message has been stored
  // This indicates if a sound event was detected
  if (myGNSS.fileBufferAvailable() >= packetLength)
  {
    uint8_t myBuffer[packetLength]; // Create our own buffer to hold the data while we write it to SD card

    myGNSS.extractFileBufferData((uint8_t *)&myBuffer, packetLength); // Extract exactly packetLength bytes from the UBX file buffer and put them into myBuffer

    digitalWrite(LED_BUILTIN, HIGH); // We will use LED_BUILTIN to indicate when data is being written to the SD card

    #ifndef KEEP_FILE_OPEN
    myFile = SD.open("TIM_TM2.ubx", FILE_WRITE); // Reopen the file
    #endif
    
    myFile.write(myBuffer, packetLength); // Write exactly packetLength bytes from myBuffer to the ubxDataFile on the SD card
    
    #ifndef KEEP_FILE_OPEN
    myFile.close(); // Close the log file after the write. Slower but safer...
    #endif

    digitalWrite(LED_BUILTIN, LOW); // Turn the LED off

    //printBuffer(myBuffer); // Uncomment this line to print the data

    // "debounce" the sound event by 250ms so we only capture one rising edge per navigation solution
    for (int i = 0; i < 250; i++)
    {
      if (readVIN() < LOW_BATT) // Check if the battery voltage is low
      {
        #ifdef KEEP_FILE_OPEN
        myFile.close(); // Close the log file immediately
        #endif
        
        break; // Stop the debounce if the battery is low
      }
      delay(1); // Wait 250 * 1ms
    }

    resetSoundTrigger(); // Reset the sound trigger. This will generate a falling edge TIM_TM2 message
  }

  // Check if we should stop logging:
  // Has the user sent serial data?
  // Or is the battery voltage low?
  // This preserves the log file, preventing it from being left open accidentally when the power is disconnected
  if ((Serial.available()) || (readVIN() < LOW_BATT))
  {
    #ifdef KEEP_FILE_OPEN
    myFile.close(); // Close the log file
    #endif
    
    Serial.println();
    Serial.println(F("Logging stopped. Freezing..."));
    while(1); // Do nothing more
  }

  Serial.print("."); // Print dots in rows of 50 while we wait for a sound event
  delay(50);
  if (++dotsPrinted > 50)
  {
    Serial.println();
    dotsPrinted = 0;
  }
}

// Print the buffer contents as Hexadecimal
// You should see:
// SYNC CHAR 1: 0xB5
// SYNC CHAR 2: 0x62
// CLASS: 0x0D for TIM
// ID: 0x03 for TM2
// LENGTH: 2-bytes Little Endian (0x1C00 = 28 bytes for TIM TM2)
// PAYLOAD: LENGTH bytes
// CHECKSUM_A
// CHECKSUM_B
// Please see the u-blox protocol specification for more details
void printBuffer(uint8_t *ptr)
{
  for (int i = 0; i < packetLength; i++)
  {
    if (ptr[i] < 16) Serial.print("0"); // Print a leading zero if required
    Serial.print(ptr[i], HEX); // Print the byte as Hexadecimal
    Serial.print(" ");
  }
  Serial.println();
}

// Read VIN / 3
// Return the true voltage (compensating for processor type)
float readVIN()
{
  float vin = analogRead(BATTVIN3);
#if defined(ARDUINO_ARDUINO_NANO33BLE)
  // nRF52840 (Arduino NANO 33 BLE) is 3.3V and defaults to 10-bit
  // BUT the Schottky diode D2 on the 3.3V line reduces VDD to 3.05V
  vin *= 3.05 / 1023.0;
  vin *= 3.0; // Correct for resistor divider
#elif defined(ARDUINO_AM_AP3_SFE_ARTEMIS_MICROMOD)
  vin *= 2.0 / 1023.0; // Artemis (APOLLO3) is 2.0V and defaults to 10-bit
  vin *= 2.5 / 1.5; // Artemis PB has a built-in 150k/100k divider
  vin *= 1.41; // Correction factor to compensate for the divider resistance
  vin *= 3.0; // Correct for resistor divider
#elif defined(ARDUINO_ARCH_ESP32)
  // ESP32 is 3.3V and defaults to 12-bit
  // Manual measurements:
  // VIN  ADC
  // 3.5V 1150
  // 4.0V 1350
  // 4.5V 1535
  // 5.0V 1735
  // 5.5V 1930
  // 6.0V 2130
  // so, VIN = (ADC / 392) + 0.565
  vin /= 392;
  vin += 0.565;
#elif defined(ARDUINO_ARCH_SAMD)
  // SAMD51 is 3.3V and defaults to 10-bit
  // BUT the Schottky diode D3 on the 3.3V line reduces VDD to 3.02V
  vin *= 3.02 / 1023.0;
  vin *= 3.0; // Correct for resistor divider
#else
  vin *= 3.0; // Undefined PB!
#endif
  return (vin);
}

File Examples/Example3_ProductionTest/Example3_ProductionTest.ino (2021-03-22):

/*
  Production Test code for the SparkFun Qwiic Sound Trigger VM1010
  By: Paul Clark
  SparkFun Electronics
  Date: March 22nd, 2021
  License: please see LICENSE.md for details

  Feel like supporting our work? Buy a board from SparkFun!
  https://www.sparkfun.com/products/17979

  Hardware Connections:
  Use a Qwiic cable to connect the Sound Trigger to your board.

  LED_BUILTIN will light up if the PCA9536 is detected correctly.
  Snap your fingers to create a sound.
  The TRIG LED on the sound trigger will light up for a second before being reset by the code.
  Snap again for another flash.

*/

#include <SparkFun_PCA9536_Arduino_Library.h> // Click here to get the library: http://librarymanager/All#SparkFun_PCA9536

PCA9536 myTrigger;

unsigned long lastTrigger = 0; // Keep a record of when the last trigger took place (millis)
boolean soundTriggered = false; // Flag when a new sound event is detected

#define VM1010_MODE 0 // The VM1010 mode pin is connected to GPIO0 on the PCA9536
#define VM1010_TRIG 1 // The VM1010 trigger pin (Dout) is connected to GPIO1 on the PCA9536

void setup()
{
  Serial.begin(115200);
  Serial.println(F("Qwiic Sound Trigger Production Test"));

  pinMode(LED_BUILTIN, OUTPUT);
  digitalWrite(LED_BUILTIN, LOW);
}

void loop()
{
  delay(250); // Try every 0.25 seconds

  Wire.begin();

  Wire.beginTransmission(0x41); // Detect PCA9536 on address 0x41
  if (Wire.endTransmission() != 0)
  {
    digitalWrite(LED_BUILTIN, LOW);
    Wire.end();
    Serial.println(F("Error: nothing detected on address 0x41"));
    return;
  }
  
  if (myTrigger.begin() == false) // Initialize the Sound Trigger PCA9536 with a begin function
  {
    digitalWrite(LED_BUILTIN, LOW);
    Wire.end();
    Serial.println(F("Error: .begin failed"));
    return;
  }

  // Configure VM1010_TRIG (GPIO1) as an input for the VM1010 trigger signal (Dout)
  PCA9536_error_t result = myTrigger.pinMode(VM1010_TRIG, INPUT);
  if (result != PCA9536_ERROR_SUCCESS)
  {
    digitalWrite(LED_BUILTIN, LOW);
    Wire.end();
    Serial.println(F("Error: .pinMode(VM1010_TRIG, INPUT) failed"));
    return;
  }

  // Configure VM1010_MODE (GPIO0) as an input for now.
  // The pull-up resistor on the sound trigger will hold the VM1010 in "Wake On Sound" mode.
  // We will configure VM1010_MODE as an output when we want to pull the MODE pin low to clear the wake-up event.
  result = myTrigger.pinMode(VM1010_MODE, INPUT);
  if (result != PCA9536_ERROR_SUCCESS)
  {
    digitalWrite(LED_BUILTIN, LOW);
    Wire.end();
    Serial.println(F("Error: .pinMode(VM1010_MODE, INPUT) failed"));
    return;
  }

  digitalWrite(LED_BUILTIN, HIGH); // PCA9536 detected OK - light up LED_BUILTIN

  // Check for a new sound (wake-up event) by reading the VM1010 Trigger (Dout) pin
  // Dout will go high when a sound is detected
  if (myTrigger.digitalRead(VM1010_TRIG) != HIGH)
  {
    Wire.end();
    Serial.println(F("All is well, sound trigger is connected, no sound detected..."));
    return; // Return leaving LED_BUILTIN lit up
  }

  // A sound has been detected!
  if (soundTriggered == false)
  {
    soundTriggered = true; // Set soundTriggered
    lastTrigger = millis(); // Update lastTrigger
  }
  
  // Check if it is time to reset the sound trigger
  if (millis() < (lastTrigger + 1000))
  {
    Wire.end();
    Serial.println(F("All is well, sound trigger is connected, sound detected, but it is not yet time to reset the trigger..."));
    return; // Return leaving LED_BUILTIN lit up
  }

  // Reset the trigger
  myTrigger.digitalWrite(VM1010_MODE, LOW); // Get ready to pull the VM1010 MODE pin low
  myTrigger.pinMode(VM1010_MODE, OUTPUT); // Change the PCA9536 GPIO0 pin to an output. It will pull the VM1010 MODE pin low
  myTrigger.pinMode(VM1010_MODE, INPUT); // Change the PCA9536 GPIO0 pin back to an input (with pull-up), so it will not 'fight' the mode button

  soundTriggered = false; // Clear soundTriggered
  
  Wire.end();
  Serial.println(F("Test passed! Sound trigger is connected. Sound detected and reset."));
  
  // Return, leaving LED_BUILTIN lit up
}

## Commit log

2021-01-26 Ready for manufacture
    [Qwiic Sound Trigger-Panel.brd, Qwiic Sound Trigger.brd, Qwiic Sound Trigger.sch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]
2021-02-04 Adding the VM1010 PROD_ID
    [Qwiic Sound Trigger.brd, Qwiic Sound Trigger.sch]
2021-03-20 Remove New-Parts
    [Qwiic Sound Trigger.brd, Qwiic Sound Trigger.sch]

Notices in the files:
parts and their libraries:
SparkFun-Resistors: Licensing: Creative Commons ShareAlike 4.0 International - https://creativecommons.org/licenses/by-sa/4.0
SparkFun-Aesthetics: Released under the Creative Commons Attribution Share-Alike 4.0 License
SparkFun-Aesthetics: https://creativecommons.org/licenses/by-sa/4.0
